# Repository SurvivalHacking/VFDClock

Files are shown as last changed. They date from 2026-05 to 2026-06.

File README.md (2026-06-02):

# VFDClock

Trasformo un semplice kit VFD in una sveglia da comodino smart! In questo video ti mostro l'hacking completo: tecnologia VFD anni '80 riproposta in chiave moderna, display azzurro ipnotico, WiFi integrato per sincronizzazione NTP e funzioni smart. Il fascino retrò incontra il futuro! 

## 📘 Descrizione

EPXX-vfdclock
Video Tutorial: https://youtu.be/dAp4a_fbGvo
vfdclock
Screenshot 2026-05-13 alle 23 02 26
Screenshot 2026-05-13 alle 23 02 49

---
## 🎛️ Schema pratico di assemblaggio

Screenshot 2026-06-01 alle 21 32 26
---
## 🎛️ Materiali

* USB-232 = https://is.gd/USB232
* VFD Clock = https://is.gd/vfdclock
* Buzzer Passivo = https://is.gd/PBUZZ
* Pulsanti 6x6x8 = https://is.gd/SW668
*  Link Affiliati

---
# 📝 Revisioni

V1.0. - 21/01/2026
*  Prima revisione

V1.1
* Cambiato lo schema di assemblaggio, in quanto esistono diverse schede USB-RS232 e alcune per qualche motivo non portano correttamente il VCC sul connettore frontale, per cui si deve prendere l'alimentazione dal connettore laterale.

---
## 🧾 Licenza

Questo progetto è distribuito con licenza
**Creative Commons – Attribuzione – Non Commerciale 4.0 Internazionale (CC BY-NC 4.0)**.

Puoi condividerlo e modificarlo liberamente, **citando l’autore**
(Davide Gatti / [survivalhacking](https://github.com/survivalhacking)) e **senza scopi commerciali**.

🔗 [https://creativecommons.org/licenses/by-nc/4.0/](https://creativecommons.org/licenses/by-nc/4.0/)

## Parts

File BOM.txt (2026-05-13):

USB-232 = https://s.click.aliexpress.com/e/_c371sBFf  ( https://is.gd/USB232 )
VFD Clock = https://s.click.aliexpress.com/e/_c3iQxRe9 ( https://is.gd/vfdclock )
Buzzer Passivo = https://s.click.aliexpress.com/e/_c3FbDqFF ( https://is.gd/PBUZZ )
Pulsanti 6x6x8 = https://s.click.aliexpress.com/e/_c4Lfz8IZ ( https://is.gd/SW668 )

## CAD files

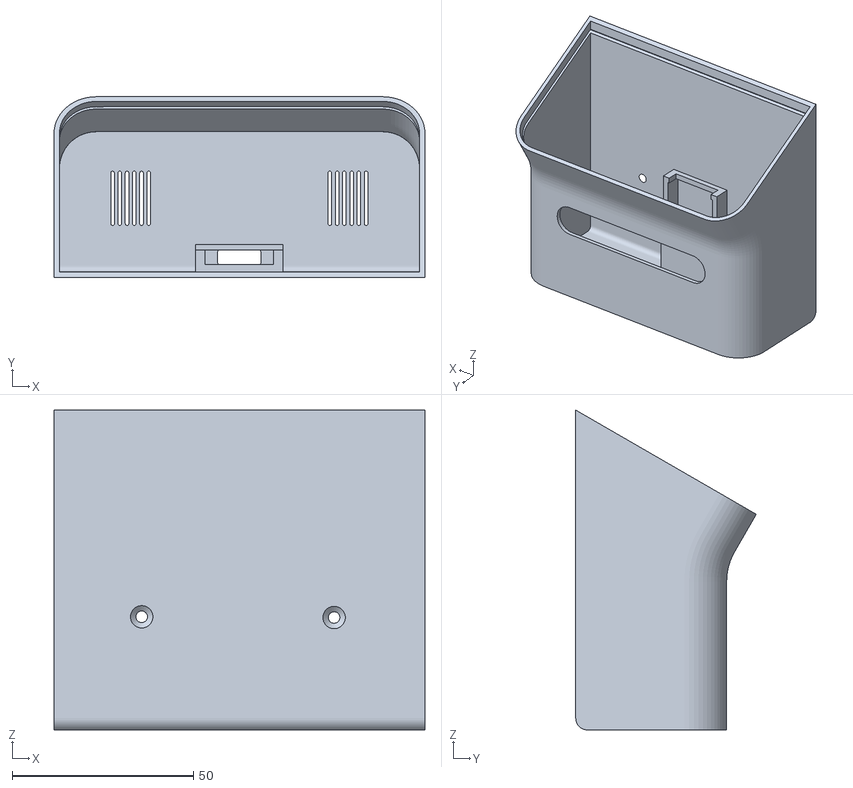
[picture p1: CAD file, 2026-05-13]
3D/Corpo.stl
102.4 x 49.9 x 88.3

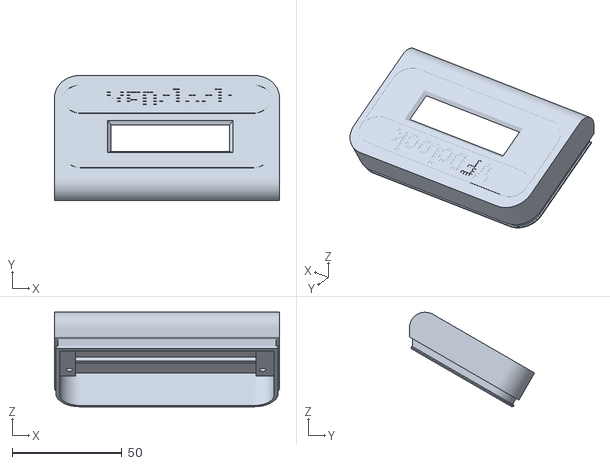
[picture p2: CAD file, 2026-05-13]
3D/Frontale Monocolore.stl
102.4 x 57.0 x 43.0

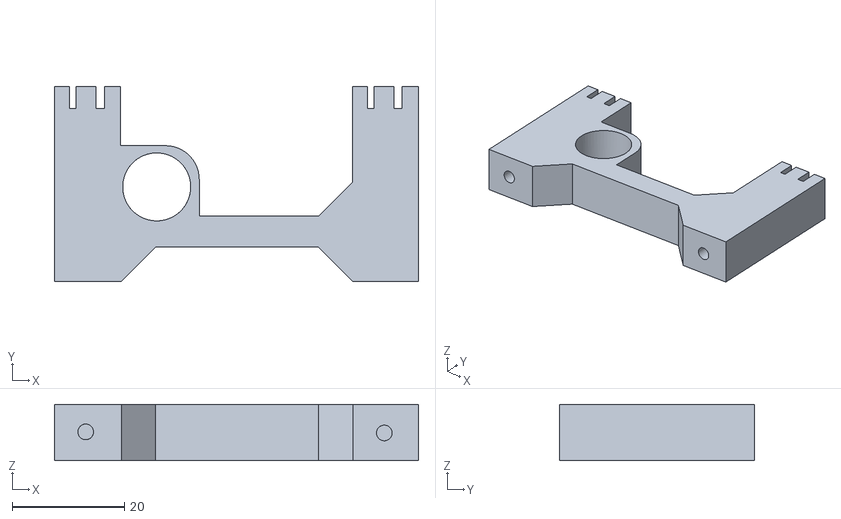
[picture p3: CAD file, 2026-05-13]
3D/Supporto.stl
64.8 x 34.7 x 10.0

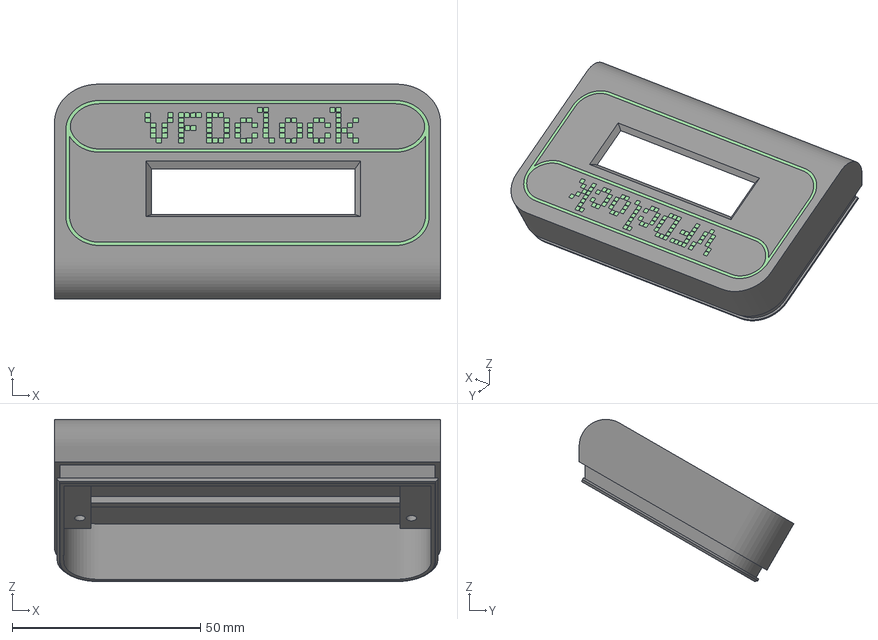
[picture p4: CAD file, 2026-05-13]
3D/Frontale Colore.3mf
102.4 x 57.0 x 43.0 mm
FRONT NERO (1)
FRONT NERO
FRONT VERDE (1)
FRONT VERDE (10)
FRONT VERDE (11)
FRONT VERDE (12)
FRONT VERDE (13)
FRONT VERDE (14)
FRONT VERDE (15)
FRONT VERDE (16)
FRONT VERDE (17)
FRONT VERDE (18)
FRONT VERDE (19)
FRONT VERDE (2)
FRONT VERDE (20)
FRONT VERDE (21)
FRONT VERDE (22)
FRONT VERDE (23)
FRONT VERDE (24)
FRONT VERDE (25)
FRONT VERDE (26)
FRONT VERDE (27)
FRONT VERDE (28)
FRONT VERDE (29)
FRONT VERDE (3)
FRONT VERDE (30)
FRONT VERDE (31)
FRONT VERDE (32)
FRONT VERDE (33)
FRONT VERDE (34)
FRONT VERDE (35)
FRONT VERDE (36)
FRONT VERDE (37)
FRONT VERDE (38)
FRONT VERDE (39)
FRONT VERDE (4)
FRONT VERDE (40)
FRONT VERDE (41)
FRONT VERDE (42)
FRONT VERDE (43)
FRONT VERDE (44)
FRONT VERDE (45)
FRONT VERDE (46)
FRONT VERDE (47)
FRONT VERDE (48)
FRONT VERDE (49)
FRONT VERDE (5)
FRONT VERDE (50)
FRONT VERDE (51)
FRONT VERDE (52)
FRONT VERDE (53)
FRONT VERDE (54)
FRONT VERDE (55)
FRONT VERDE (56)
FRONT VERDE (57)
FRONT VERDE (58)
FRONT VERDE (59)
FRONT VERDE (6)
FRONT VERDE (60)
FRONT VERDE (61)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

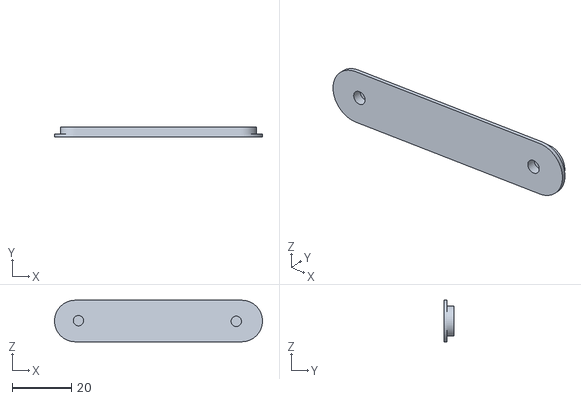
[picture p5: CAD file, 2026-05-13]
3D/PULSANTE.stl
70.0 x 3.50 x 14.0

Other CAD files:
3D/VFDClock.f3d

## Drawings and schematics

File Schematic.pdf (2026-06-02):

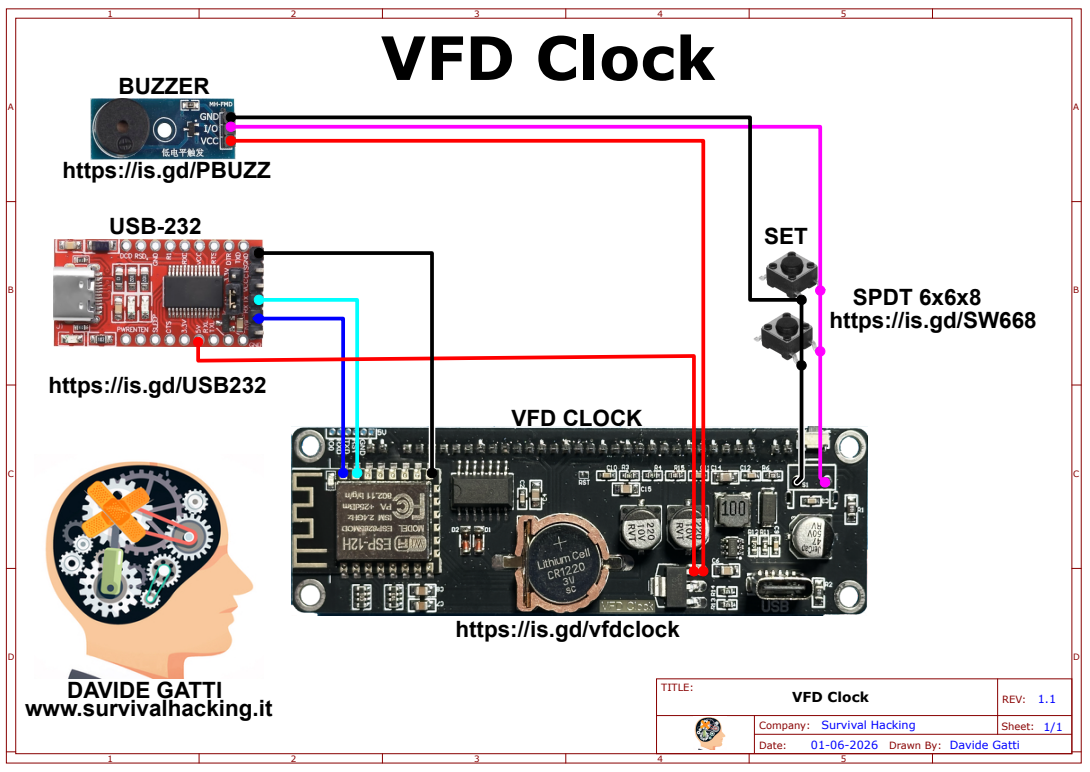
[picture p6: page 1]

https://is.gd/PBUZZ

https://is.gd/vfdclock

TITLE: | REV: 1.1

Company: Survival Hacking | Sheet: 1/1

Drawn By: Davide Gatti

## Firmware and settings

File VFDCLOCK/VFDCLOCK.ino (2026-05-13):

// VFD Clock V1.0 by Davide Gatti - Survival Hacking - www.survivalhacking.it - 12/2025
// 
// Implementazione software per il dispositivo hardware aliexpress: https://is.gd/vfdclock 
// E' stato fatto un reverse engineering dei collegamenti dei vari dispositivi e riscritto un firmware più completo e configurabile 
// per un orologio / sveglia collegato alla rete WIFI per il recupero data/ora viam NTP e utilizzo dell'RTC come backup.
// E' stata implementata anche una pagina WEB per la configurazione avanzata.
// 
// Funzionamento:
// * Al primo avvio, usando un telefonino, collegarsi alla rete VFDClock e impostare la connseeione WIFI. Se una volta collegato
//   non apparirà la schermata di impostazioni, andare con il browser all'indirizzo 192.16.4.1 
// * Premendo il pulsante è possibile vedere in sequenza Data/Sveglia/Stato sveglia/Indirizzo IP
// * Premendo il pulsante per 2 secondi si passa alla modalità di regolazione della sveglia
//   in quella modalità premendo il pulsante brevemente si potrà incrementare l'elemento selezionato. Tenendo premuto a lungo, si passerà
//   all'elemento successivo. Premendo nuovamente a lungo sarà possibile selezionare se attivare o disattivare la sveglia.
//   Premendo nuovamente a lungo sarà possibile ritornare alla modalità orologio.
// * Premendo per oltre 8 secondi il pulsante si eseguirà il reset delle impostaizoni del WIFI.
// 
// Se la sveglia è attiva i puntini separatori dell'orario, lampeggiano, se invece non c'è nessuna sveglia i puntini separatori rimarranno fissi.
// 
// Tramite pagina WEB sarà possibile fare ulteriori regolazioni
// * Commutazione automatica ora/data con cadenza programmabile
// * Regolazione luminosità su tre fasce orarie.
// * Impostazione fuso orario e ora legale
// * impostazione allarme
// * impostazione animazione modalità orologio
// * reset / impostazione WIFI
// 
// 
// 
// 
// Software implementation for the Aliexpress hardware device: https://is.gd/vfdclock
// The connections of the various devices were reverse engineered and a more complete and configurable firmware was rewritten 
// for a clock/alarm connected to the WiFi network for date/time retrieval via NTP and use of the RTC as a backup.
// A web page for advanced configuration has also been implemented.
// 
// Operation:
// * When starting up for the first time, use a cell phone to connect to the VFDClock network and set up the WiFi connection. If the settings screen does not appear once connected,
//   go to 192.16.4.1 in your browser. 
// * Pressing the button allows you to view the date, alarm, alarm status, and IP address in sequence.
// * Pressing the button for 2 seconds will switch to alarm adjustment mode.
//   In this mode, pressing the button briefly will increase the selected item. Holding it down for a long time will switch
//   to the next item. Pressing and holding again will allow you to select whether to activate or deactivate the alarm.
//   Pressing and holding again will return you to clock mode.
// * Pressing the button for more than 8 seconds will reset the WIFI settings.
// 
// If the alarm is active, the dots separating the time will flash; if there is no alarm, the dots will remain steady.
//
// Further adjustments can be made via the web page
// * Automatic time/date changeover at programmable intervals
// * Brightness adjustment in three time bands.
// * Time zone and daylight saving time settings
// * Alarm settings
// * Clock mode animation settings
// * Reset/WIFI settings
//
//
//
// ============================================================================
// LIBRERIE / LIBRARIES
// ============================================================================
#include <ESP8266WiFi.h>
#include <ESP8266WebServer.h>
#include <DNSServer.h>
#include <WiFiUdp.h>
#include <NTPClient.h>
#include <Wire.h>
#include <TimeLib.h>
#include <Timezone.h>
#include <EEPROM.h>

// ============================================================================
// DEFINIZIONI PIN / PIN DEFINITIONS
// ============================================================================
#define VFD_MOSI 14         // Pin MOSI per VFD / VFD MOSI pin
#define VFD_CLK 12          // Pin Clock per VFD / VFD Clock pin
#define VFD_CS 13           // Pin Chip Select per VFD / VFD Chip Select pin
#define VFD_RST 16          // Pin Reset per VFD / VFD Reset pin
#define BUTTON_PIN 0        // Pulsante multifunzione / Multifunction button
#define BUZZER_PIN 0        // Buzzer per sveglia / Alarm buzzer

#define SDA_PIN 5           // Pin I2C SDA per RTC / I2C SDA pin for RTC
#define SCL_PIN 4           // Pin I2C SCL per RTC / I2C SCL pin for RTC
#define RTC_ADDRESS 0x32    // Indirizzo I2C RX8025T / RX8025T I2C address
#define WIFI_TIMEOUT 60000  // Timeout connessione WiFi (ms) / WiFi connection timeout (ms)

// ============================================================================
// CONFIGURAZIONE TIMEZONE ITALIA / ITALY TIMEZONE CONFIGURATION
// ============================================================================
TimeChangeRule CEST = { "CEST", Last, Sun, Mar, 2, 120 };  // Ora legale / Daylight saving time
TimeChangeRule CET = { "CET", Last, Sun, Oct, 3, 60 };     // Ora solare / Standard time
Timezone italyTZ(CEST, CET);

// ============================================================================
// OGGETTI GLOBALI / GLOBAL OBJECTS
// ============================================================================
WiFiUDP ntpUDP;
NTPClient timeClient(ntpUDP, "pool.ntp.org", 0, 60000);
ESP8266WebServer server(80);
DNSServer dnsServer;

// ============================================================================
// VARIABILI GLOBALI / GLOBAL VARIABLES
// ============================================================================
static char VFD_Dimming = 0x8f;          // Livello luminosità VFD / VFD brightness level
unsigned long lastNTPSync = 0;            // Ultimo sync NTP / Last NTP sync
unsigned long lastDisplayUpdate = 0;      // Ultimo aggiornamento display / Last display update
unsigned long lastDateDisplay = 0;        // Ultima visualizzazione data / Last date display
bool wifiConnected = false;               // Stato connessione WiFi / WiFi connection status
bool apMode = false;                      // Modalità Access Point / Access Point mode
unsigned long apModeStart = 0;            // Inizio modalità AP / AP mode start time
bool rtcFound = false;                    // RTC rilevato / RTC detected
bool webServerStarted = false;            // Web server avviato / Web server started
bool showingDate = false;                 // Mostrando data / Showing date
unsigned long dateShowStart = 0;          // Inizio visualizzazione data / Date display start

// ============================================================================
// GESTIONE SVEGLIA / ALARM MANAGEMENT
// ============================================================================
enum AlarmMode {
  ALARM_IDLE,         // Modalità normale / Normal mode
  ALARM_SET_HOUR,     // Imposta ora / Set hour
  ALARM_SET_MINUTE,   // Imposta minuto / Set minute
  ALARM_SET_ONOFF     // Attiva/Disattiva / Enable/Disable
};

AlarmMode alarmMode = ALARM_IDLE;
unsigned long lastBlinkTime = 0;
bool blinkState = false;
bool alarmIsRinging = false;              // Sveglia in corso / Alarm ringing
bool blinkSeparators = false;             // Lampeggio separatori ":" / Colon separators blinking
unsigned long alarmRingingStart = 0;
int alarmBeepPhase = 0;                   // Fase beep crescente / Crescendo beep phase
unsigned long lastBeepTime = 0;

// ============================================================================
// STRUTTURA CONFIGURAZIONE / CONFIGURATION STRUCTURE
// ============================================================================
struct ClockConfig {
  int tzOffsetMinutes;              // Offset fuso orario / Timezone offset
  uint8_t dstEnabled;               // Ora legale auto / Auto DST
  uint8_t b1Hour;                   // Fascia 1: ora / Band 1: hour
  uint8_t b1Minute;                 // Fascia 1: minuto / Band 1: minute
  uint8_t b1Level;                  // Fascia 1: luminosità / Band 1: brightness
  uint8_t b2Hour;                   // Fascia 2: ora / Band 2: hour
  uint8_t b2Minute;                 // Fascia 2: minuto / Band 2: minute
  uint8_t b2Level;                  // Fascia 2: luminosità / Band 2: brightness
  uint8_t b3Hour;                   // Fascia 3: ora / Band 3: hour
  uint8_t b3Minute;                 // Fascia 3: minuto / Band 3: minute
  uint8_t b3Level;                  // Fascia 3: luminosità / Band 3: brightness
  uint8_t showDateEnabled;          // Mostra data periodicamente / Show date periodically
  uint16_t dateIntervalSeconds;     // Intervallo visualizzazione data / Date display interval
  uint8_t scrollAnimationEnabled;   // Animazione scroll / Scroll animation
  uint8_t alarmHour;                // Ora sveglia / Alarm hour
  uint8_t alarmMinute;              // Minuto sveglia / Alarm minute
  uint8_t alarmEnabled;             // Sveglia attiva / Alarm enabled
  uint8_t wifiResetFlag;            // Flag reset WiFi / WiFi reset flag
  uint8_t reserved[1];              // Riservato / Reserved
};

ClockConfig cfg;

const int EEPROM_SIZE = 512;
const int EEPROM_CFG_ADDR = 100;

// ============================================================================
// STATI BOOT / BOOT STATES
// ============================================================================
enum BootState {
  BOOT_SCROLLING_INTRO,   // Mostra intro / Show intro
  BOOT_WIFI_CONNECTING,   // Connessione WiFi / WiFi connecting
  BOOT_WIFI_OK,           // WiFi connesso / WiFi connected
  BOOT_SHOW_IP,           // Mostra IP / Show IP
  BOOT_NTP_SYNC,          // Sincronizzazione NTP / NTP sync
  BOOT_DONE               // Boot completato / Boot done
};

BootState bootState = BOOT_SCROLLING_INTRO;
unsigned long bootStateTime = 0;
unsigned long wifiConnectStart = 0;
int wifiDots = 0;

// ============================================================================
// COMUNICAZIONE SPI VFD / VFD SPI COMMUNICATION
// ============================================================================
// Trasferimento SPI bit-banging / SPI bit-banging transfer
void SPI_transfer_bitbang(uint8_t data) {
  for (int i = 0; i < 8; i++) {
    digitalWrite(VFD_MOSI, bitRead(data, i));
    digitalWrite(VFD_CLK, HIGH);
    delayMicroseconds(1);
    digitalWrite(VFD_CLK, LOW);
    delayMicroseconds(1);
  }
}

// ============================================================================
// PATTERN CARATTERI VFD / VFD CHARACTER PATTERNS
// ============================================================================
// Pattern 5x7 per cifre 0-9 e caratteri speciali / 5x7 patterns for digits 0-9 and special chars
const uint8_t digitPatterns[14][5] = {
  { 0x3E, 0x51, 0x49, 0x45, 0x3E },  // 0
  { 0x00, 0x42, 0x7F, 0x40, 0x00 },  // 1
  { 0x42, 0x61, 0x51, 0x49, 0x46 },  // 2
  { 0x21, 0x41, 0x45, 0x4B, 0x31 },  // 3
  { 0x18, 0x14, 0x12, 0x7F, 0x10 },  // 4
  { 0x27, 0x45, 0x45, 0x45, 0x39 },  // 5
  { 0x3C, 0x4A, 0x49, 0x49, 0x30 },  // 6
  { 0x01, 0x71, 0x09, 0x05, 0x03 },  // 7
  { 0x36, 0x49, 0x49, 0x49, 0x36 },  // 8
  { 0x06, 0x49, 0x49, 0x29, 0x1E },  // 9
  { 0x00, 0x36, 0x36, 0x00, 0x00 },  // : (due punti)
  { 0x14, 0x08, 0x3E, 0x08, 0x14 },  // * (stella)
  { 0x40, 0x30, 0x0C, 0x03, 0x00 },  // / (slash)
  { 0x00, 0x00, 0x00, 0x00, 0x00 }   // (spazio)
};

// Converte carattere in indice pattern / Convert character to pattern index
uint8_t getPatternIndex(char c) {
  if (c >= '0' && c <= '9') return c - '0';
  if (c == ':') return 10;
  if (c == '*') return 11;
  if (c == '/' || c == '\\') return 12;
  return 13;
}

// ============================================================================
// FUNZIONI VFD / VFD FUNCTIONS
// ============================================================================

// Scrive carattere custom in memoria VFD / Write custom character to VFD memory
void VFD_WriteCustomChar(uint8_t addr, const uint8_t pattern[5]) {
  if (addr > 7) return;
  digitalWrite(VFD_CS, LOW);
  SPI_transfer_bitbang(0x40 + addr * 5);
  for (int i = 0; i < 5; i++) {
    SPI_transfer_bitbang(pattern[i]);
  }
  digitalWrite(VFD_CS, HIGH);
  delayMicroseconds(50);
}

// Mostra carattere custom su posizione / Show custom character at position
void VFD_ShowCustomChar(uint8_t pos, uint8_t customAddr) {
  if (pos > 7 || customAddr > 7) return;
  digitalWrite(VFD_CS, LOW);
  SPI_transfer_bitbang(0x20 + pos);
  SPI_transfer_bitbang(customAddr);
  digitalWrite(VFD_CS, HIGH);
}

// ============================================================================
// ANIMAZIONE SCROLL / SCROLL ANIMATION
// ============================================================================

// Stato animazione / Animation state
struct AnimationState {
  char currentDisplay[8];
  char targetDisplay[8];
  int8_t frameOffset[8];
  bool animating[8];
};

AnimationState animState = {
  { ' ', ' ', ' ', ' ', ' ', ' ', ' ', ' ' },
  { ' ', ' ', ' ', ' ', ' ', ' ', ' ', ' ' },
  { 0, 0, 0, 0, 0, 0, 0, 0 },
  { false, false, false, false, false, false, false, false }
};
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
void loop() {
  unsigned long now = millis();

  // Gestione web server / Web server handling
  if (webServerStarted) {
    server.handleClient();
    if (apMode) dnsServer.processNextRequest();
  }

  // Macchina a stati boot / Boot state machine
  switch (bootState) {

    // ========================================================================
    // INTRO SCROLLING / SCROLLING INTRO
    // ========================================================================
    case BOOT_SCROLLING_INTRO:
      {
        static bool shown = false;
        if (!shown) {
          scrollTextComplete("VFD CLOCK BY DAVIDE GATTI", 8000);
          shown = true;
          bootStateTime = now;
        }
        // Controlla credenziali WiFi salvate / Check saved WiFi credentials
        EEPROM.begin(EEPROM_SIZE);
        bool hasCred = (EEPROM.read(0) != 0 && EEPROM.read(0) != 0xFF);
        if (hasCred) {
          char ssid[32] = { 0 }, password[64] = { 0 };
          for (int i = 0; i < 32; i++) {
            ssid[i] = EEPROM.read(i);
            if (ssid[i] == 0) break;
          }
          for (int i = 0; i < 64; i++) {
            password[i] = EEPROM.read(32 + i);
            if (password[i] == 0) break;
          }
          EEPROM.end();
          Serial.print("Connecting: ");
          Serial.println(ssid);
          WiFi.mode(WIFI_STA);
          WiFi.begin(ssid, password);
          wifiConnectStart = now;
          wifiDots = 0;
          bootState = BOOT_WIFI_CONNECTING;
          bootStateTime = now;
        } else {
          EEPROM.end();
          startAccessPoint();
          bootState = BOOT_DONE;
        }
      }
      break;

    // ========================================================================
    // CONNESSIONE WIFI / WIFI CONNECTING
    // ========================================================================
    case BOOT_WIFI_CONNECTING:
      {
        if (now - bootStateTime >= 500) {
          bootStateTime = now;
          char c[8] = { 'W', 'I', 'F', 'I', ' ', ' ', ' ', ' ' };
          for (int i = 0; i < (wifiDots % 4); i++) c[5 + i] = '.';
          VFD_DISP(c);
          wifiDots++;
        }
        if (WiFi.status() == WL_CONNECTED) {
          wifiConnected = true;
          bootState = BOOT_WIFI_OK;
          bootStateTime = now;
          Serial.println("\nWiFi OK");
        } else if (now - wifiConnectStart > WIFI_TIMEOUT) {
          Serial.println("\nTimeout");
          WiFi.disconnect();
          startAccessPoint();
          bootState = BOOT_DONE;
        }
      }
      break;

    // ========================================================================
    // WIFI CONNESSO / WIFI CONNECTED
    // ========================================================================
    case BOOT_WIFI_OK:
      {
        static bool shown = false;
        if (!shown) {
          char ok[8] = { 'W', 'I', 'F', 'I', ' ', 'O', 'K', '!' };
          VFD_DISP(ok);
          shown = true;
        }
        if (now - bootStateTime >= 1000) {
          bootState = BOOT_SHOW_IP;
          bootStateTime = now;
        }
      }
      break;

    // ========================================================================
    // MOSTRA IP / SHOW IP
    // ========================================================================
    case BOOT_SHOW_IP:
      {
        static bool shown = false;
        if (!shown) {
          IPAddress ip = WiFi.localIP();
          scrollTextComplete("IP=" + ip.toString(), 5000);
          shown = true;
        }
        startWebServer();
        timeClient.begin();
        bootState = BOOT_NTP_SYNC;
        bootStateTime = now;
      }
      break;

    // ========================================================================
    // SINCRONIZZAZIONE NTP / NTP SYNCHRONIZATION
    // ========================================================================
    case BOOT_NTP_SYNC:
      {
        static int att = 0;
        static unsigned long lastAtt = 0;
        if (now - lastAtt > 2000 && att < 5) {
          lastAtt = now;
          att++;
          if (syncNTPtoRTC()) {
            lastNTPSync = millis();
            bootState = BOOT_DONE;
            att = 0;
          }
        } else if (att >= 5) {
          Serial.println("NTP failed");
          bootState = BOOT_DONE;
          att = 0;
        }
      }
      break;

    // ========================================================================
    // FUNZIONAMENTO NORMALE / NORMAL OPERATION
    // ========================================================================
    case BOOT_DONE:
      {
        // Stabilizzazione pulsante / Button stabilization
        static unsigned long bootDoneStart = 0;
        static bool bootDoneInit = false;
        if (!bootDoneInit) {
          bootDoneStart = millis();
          bootDoneInit = true;
        }
        bool stable = (millis() - bootDoneStart > 2000);

        // Modalità Access Point / Access Point mode
        if (apMode) {
          static unsigned long lastTog = 0;
          static bool showIP = false;
          if (millis() - lastTog > 2000) {
            lastTog = millis();
            showIP = !showIP;
            char d[8];
            if (showIP) strcpy(d, "192.4.1 ");
            else strcpy(d, "Portal  ");
            VFD_DISP(d);
          }
          break;
        }

        // Funzionamento stabile / Stable operation
        if (stable) {
          checkAlarmTrigger();

          // Lampeggio separatori se sveglia attiva / Separator blinking if alarm enabled
          static unsigned long lastBlinkUpdate = 0;
          if (cfg.alarmEnabled && (now - lastBlinkUpdate >= 500)) {
            lastBlinkUpdate = now;
            blinkSeparators = !blinkSeparators;
          }

          // ----------------------------------------------------------------
          // SVEGLIA IN CORSO / ALARM RINGING
          // ----------------------------------------------------------------
          if (alarmIsRinging) {
            updateAlarmSound();

            // Ferma sveglia con pulsante / Stop alarm with button
            static int lastBtnState = HIGH;
            int btnState = digitalRead(BUTTON_PIN);
            if (btnState == LOW && lastBtnState == HIGH) {
              stopAlarm();
              delay(300);
            }
            lastBtnState = btnState;

            // Aggiorna display durante sveglia / Update display during alarm
            unsigned long displayInterval = 500;
            if (now - lastDisplayUpdate >= displayInterval) {
              lastDisplayUpdate = now;
              int h, m, s, d, mon, y;
              rtcReadTime(h, m, s, d, mon, y);
              uint8_t lvl = getDimmingForCurrentTime(h, m);
              VFD_Dimming = lvl;
              VFD_SetDimming(VFD_Dimming);

              char t[9];
              char sep = cfg.alarmEnabled ? (blinkSeparators ? ' ' : ':') : ':';
              sprintf(t, "%02d%c%02d%c%02d", h, sep, m, sep, s);
              if (cfg.scrollAnimationEnabled) VFD_DISP_Scroll(t);
              else VFD_DISP(t);
            }

          // ----------------------------------------------------------------
          // FUNZIONAMENTO NORMALE / NORMAL OPERATION
          // ----------------------------------------------------------------
          } else {
            // Gestione pulsante per info / Button handling for info
            static int lastInfoBtnState = HIGH;
            static unsigned long infoBtnPressTime = 0;
            static bool infoBtnPressed = false;
            static int infoScreen = 0;  // 0=ora, 1=data, 2=alarm, 3=stato, 4=IP
            static unsigned long infoDisplayStart = 0;

            int infoBtnState = digitalRead(BUTTON_PIN);

            // Rileva pressione / Detect press
            if (infoBtnState == LOW && lastInfoBtnState == HIGH) {
              infoBtnPressed = true;
              infoBtnPressTime = now;
            }

            // Reset WiFi con pressione >8 secondi in schermata orologio
            if (infoBtnState == LOW && infoBtnPressed && infoScreen == 0 && alarmMode == ALARM_IDLE) {
              if (now - infoBtnPressTime > 8000) {
                char r[8] = { 'R', 'E', 'S', 'E', 'T', ' ', ' ', ' ' };
                VFD_DISP(r);
                clearWiFiCredentials();
                delay(2000);
                ESP.restart();
              }
            }

            // Rileva rilascio / Detect release
            if (infoBtnState == HIGH && lastInfoBtnState == LOW && infoBtnPressed) {
              unsigned long dur = now - infoBtnPressTime;
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

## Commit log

2026-05-13 File per stampa 3D
    [Corpo.stl, Frontale Colore.3mf, Frontale Monocolore.stl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]
2026-05-13 Sketch per arduino IDE
2026-05-13 Schema di assemblaggio
2026-05-13 Elenco Materiali
2026-06-02 Revise README with new assembly schema and notes
    Updated assembly diagram and added notes on power supply connections.
2026-06-02 Practical schematic / schema pratico
